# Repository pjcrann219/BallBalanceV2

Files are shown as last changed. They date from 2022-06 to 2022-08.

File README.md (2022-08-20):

# BallBalanceV2
New and improved ball balancing system

Sense: Webcam w/ OpenCV to get ball position  
Reason: Python running on laptop caluclates response angles w/ PID control and sends to arduino  
Act: Arduino controls 2 servo motors w/ arm joints connecting to platform  

### Materials:  
  Arduino MKR 1010  
  Logitech WebCam  
  2 MG995 servo motors  
  Surface cut from 3-ring binder  
  Ball to balance  
  3D-printed parts  
    Center joint(2 Pieces)  
    Arm joint (2 pieces each)  
    
### Improvements from V1:  
  Computer vision vs unfiltered 4-wire rewsistive touch screen gave more accurate position measurements  
  3D printed joints made struture much stronger, less wiggle room between motor and surface gave more accurate tilt outputs  
    
### Limitations:  
  Cheap motors with slow angular velocity made response to large impulses very hard  
  Golf ball used - dimples on surface made fine control hard  
 
## System Diagram
 

## Current Demo
https://user-images.githubusercontent.com/48891310/174686334-3ba37f21-3474-40dd-aec3-4881e36f26b0.mp4

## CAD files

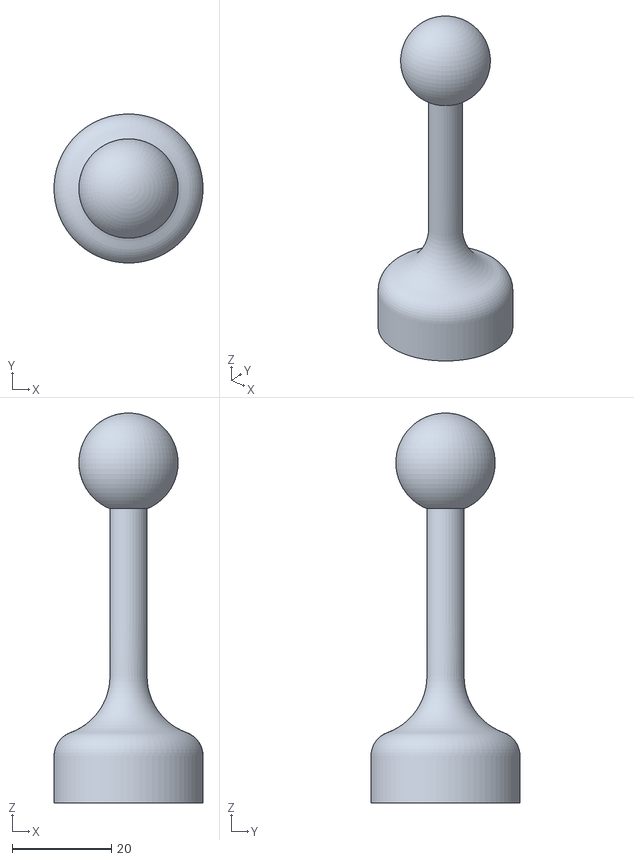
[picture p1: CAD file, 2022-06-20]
Balance Ball STL/CenterJoint_1_final.stl
30.0 x 30.0 x 78.5

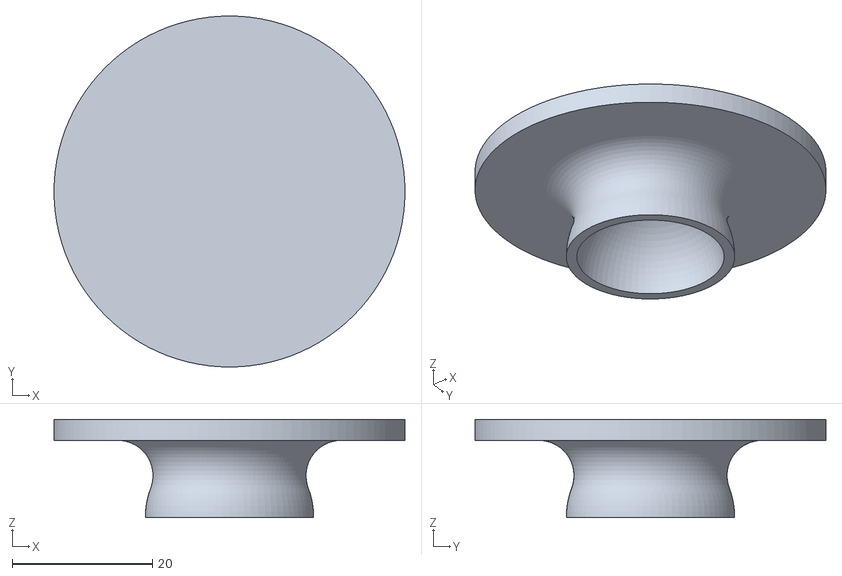
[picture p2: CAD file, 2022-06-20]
Balance Ball STL/CenterJoint_2_final.stl
50.0 x 50.0 x 14.0

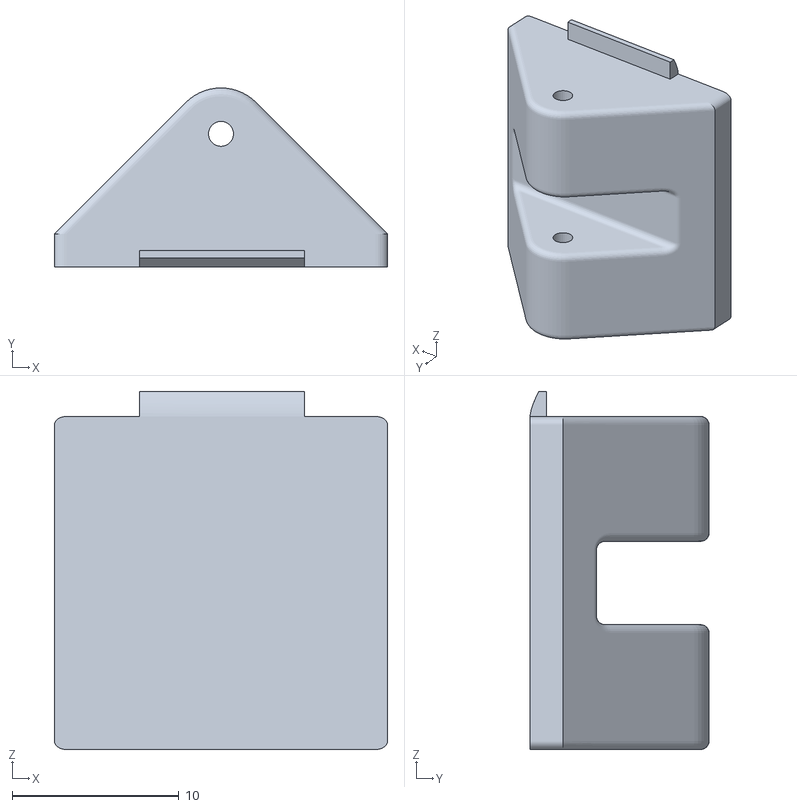
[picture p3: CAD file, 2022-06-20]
Balance Ball STL/ArmJoint_final.stl
20.0 x 10.8 x 21.5

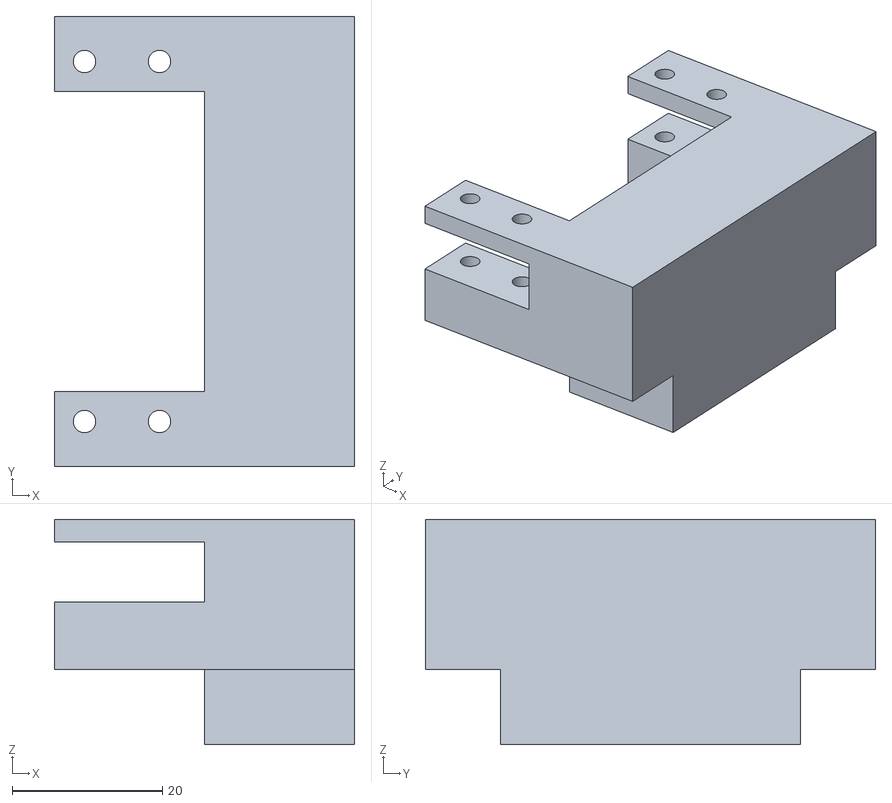
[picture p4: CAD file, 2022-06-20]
Balance Ball STL/ServoHold_final.stl
40.0 x 60.0 x 30.0

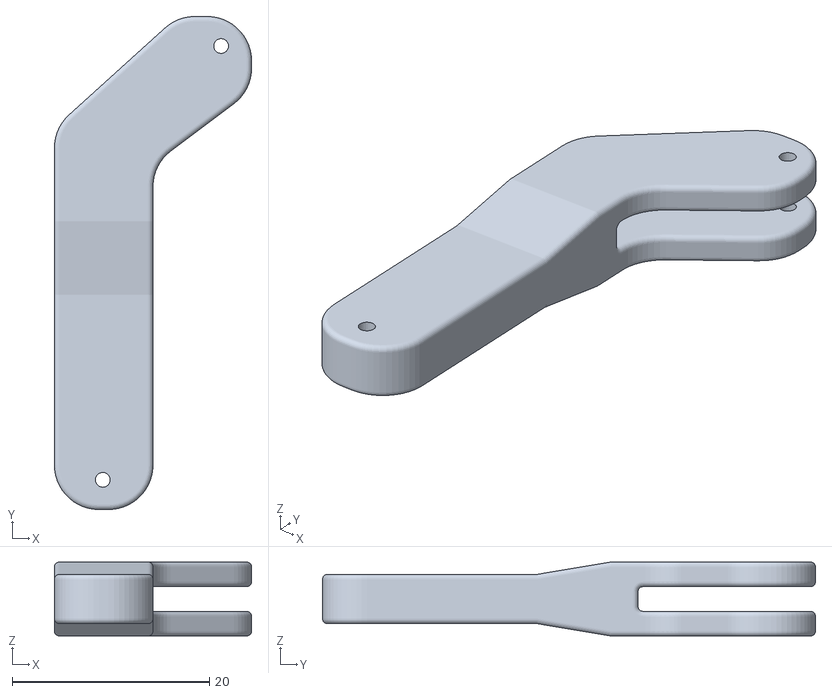
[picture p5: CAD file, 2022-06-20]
Balance Ball STL/Arm_final.stl
20.0 x 50.0 x 7.50

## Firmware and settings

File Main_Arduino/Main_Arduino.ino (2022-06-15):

#include <Servo.h>

Servo servo_x;  // Servo controls X axis tilt
Servo servo_y;  // Servo controls Y axis tilt

int x = 90;
int y = 90;

int x_offset = 5;
int y_offset = 5;

void setup() {
  Serial.begin(115200);
  servo_x.attach(6);
  servo_y.attach(7);
}

void loop() {
    
    if(Serial.available() > 0) {
      char c = Serial.read();
      if (c == 'S'){  // Servo Position Data
        updateAngles();
      }else if(c == 'C'){ // Calibration routine
        calibrate();
      }
    }
}

// Used to update servo positions
void updateAngles() {
  char x1 = Serial.read();
  char x2 = Serial.read();
  char x3 = Serial.read();
  
  x = 100 * int(x1) + 10 * int(x2) + int(x3) - 111 * '0';

  char y1 = Serial.read();
  char y2 = Serial.read();
  char y3 = Serial.read();
  
  y = 100 * int(y1) + 10 * int(y2) + int(y3) - 111 * '0';

  servo_x.write(180 - (x-5));
  servo_y.write(180 - (y-5));
//  Serial.println("X: " + String(x) + "\tY: " + String(y));
}

// Used to calibrate tilt
void calibrate(){
  Serial.println("Calibrate");
}

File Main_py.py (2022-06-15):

from functions import *
import cv2
import time
import math

# Connect to arduino via serial
port = '/dev/cu.usbmodem1442201'
arduino = connect_arduino(port)
# Set to no tilt
send_data(arduino, 90, 90)

# Settup camera
cam = cv2.VideoCapture(0)

while True:
    ret, img = cam.read()
    img = cv2.flip(img[0:690, 300:929], -1)
    worked, x_center, y_center, scale_pixle, result = calibrate_camera(img)
    if worked:
        print(scale_pixle)
        # cv2.startWindowThread()
        # cv2.imshow('mask', result)
        # cv2.waitKey(0)
        # cv2.destroyAllWindows()
        # cv2.waitKey(1)
        break

print('Center and Scale found')

scale_mm = 135
scale = scale_mm / scale_pixle
x_setpoint = y_setpoint = 0

Kp_x = Kp_y = 0.5
Kd_x = Kd_y = 0.2

t_start = time.time()
t_last = t_start

x_last = x_setpoint
y_last = y_setpoint

while True:
    ret, img = cam.read()
    img = cv2.flip(img[0:690, 300:929], -1)
    found, x_pixle, y_pixle, result = findBall(img)
    if found:
        # Calculate x and y position from center in mm
        x = (x_pixle - x_center) * scale
        y = (y_center - y_pixle) * scale

        x_error = x - x_setpoint
        y_error = y - y_setpoint

        dT = time.time() - t_last
        t_last = time.time()

        x_der = (x_error - x_last) / dT
        y_der = (y_error - y_last) / dT

        x_last = x_error
        y_last = y_error

        x_angle = 90 + Kp_x * x_error + Kd_x * x_der
        y_angle = 90 + Kp_y * y_error + Kd_y * y_der

        if x_angle < 0: x_angle = 0
        else:
            if x_angle > 180: x_angle = 180
        if y_angle < 0: y_angle = 0
        else: 
            if y_angle > 180: y_angle = 180
        send_data(arduino, int(x_angle), int(y_angle))
        # print('X_angle: ' + str(x_angle) + ', Y_angle: ' + str(y_angle))

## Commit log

2022-06-15 Initial Commit of Python function/main and arduino main
2022-06-20 Added STL files
    [ArmJoint_final.stl, Arm_final.stl, CenterJoint_1_final.stl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]
